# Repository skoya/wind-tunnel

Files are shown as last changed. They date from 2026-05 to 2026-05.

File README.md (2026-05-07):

# KOYA Cooling Stand

Modular OpenSCAD design for a dual Raspberry Pi 5 + UGREEN NVMe + Mac mini M4 airflow stand.

## Hardware concept

- Front 140mm USB-powered fan cools the lower duct.
- UGREEN Thunderbolt/USB-C NVMe enclosure sits below the Pi stacks.
- Two Raspberry Pi 5 + Waveshare PoE M.2 HAT+ B stacks sit above the UGREEN bay.
- Mac mini M4 sits on top in low guide rails.
- Second 140mm fan blows upward toward the Mac mini underside.
- Rear remains open for exhaust and cable routing.

## Main CAD file

Place this in the repo root:

`dual_pi5_macmini_v2_1_corrected_stack_koya.scad`

## Exporting parts

```bash
bash scripts/export_parts.sh dual_pi5_macmini_v2_1_corrected_stack_koya.scad
```

Exports go into `exports/`.

## Validating

```bash
bash scripts/validate_scad.sh dual_pi5_macmini_v2_1_corrected_stack_koya.scad
```

## Important

The assembly export is for inspection only. Print individual parts.

### Support-light base notes

The Pi cassette support is now a separate `pi_frame_bridge` part. The base has four low PLA clip pegs around the UGREEN bay, avoiding the old integrated cantilever gantry and avoiding screws/inserts.

Recommended print/assembly order:

1. Print `base_duct.stl` upright.
2. Print `pi_frame_bridge.stl` as exported; it is flipped upside-down so the cross beams sit on the bed and the posts grow upward.
3. Press the Pi frame C-slotted feet down over the four tapered PLA pegs on the base.
4. Slide/fit the Pi cassettes into the removable frame.

Cable management in the base should use the floor zip-tie slots rather than printed overhanging cable lips.

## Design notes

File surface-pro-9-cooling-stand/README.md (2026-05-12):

# Surface Pro 9 heatsink/fan cooling stand

Current recommended version: **v2**.

Designed around Bobby's actual stack:

- Surface Pro 9 rests directly on aluminium.
- Heatsink: **300 x 140 x 20 mm**, flat face up.
- Noctua fan: **200 x 200 x 30 mm** underneath.
- Printed parts locate/support the metal and fan; they do **not** sit between Surface and heatsink.

## v3 - smoother enclosed version

Current aesthetic candidate: **v3**.

v3 keeps the v2 airflow/fastening logic but makes the stand less like scaffolding:

- rounded charcoal side shrouds and front/rear fascias;
- warm Noctua-style accent on the front catch and removable dust grille;
- fan is mostly hidden in normal use;
- side/front/rear vents keep airflow moving without exposing the whole fan;
- removable `bottom_dust_grille_v3.stl` lets you access the fan for dust cleaning;
- Surface still touches only the exposed aluminium heatsink.

Print for v3:

- `left_rail_v3.stl`
- `right_rail_v3.stl`
- `fan_tray_front_v3.stl`
- `fan_tray_rear_v3.stl`
- `front_lip_v3.stl`
- `rear_keeper_v3.stl`
- `bottom_dust_grille_v3.stl`

Inspect:

- `surface9_heatsink_fan_stand_v3.scad`
- `assembly_v3.stl`
- `preview_v3.png`
- `surface-pro-9-cooling-stand-v3.zip`

## Why v2 exists

v1 proved the layout, but had two real problems:

1. The fan did not have an explicit intake path if the tray sat flat on a desk.
2. The parts were not clearly fastened together.

v2 fixes both.

## v2 parts to print

Print these:

- `left_rail_v2.stl`
- `right_rail_v2.stl`
- `fan_tray_front_v2.stl`
- `fan_tray_rear_v2.stl`
- `front_lip_v2.stl`
- `rear_keeper_v2.stl`

Inspection/reference:

- `surface9_heatsink_fan_stand_v2.scad`
- `assembly_v2.stl` - assembled preview with reference solids for fan/heatsink/Surface
- `printable_frame_v2.stl` - assembled printed parts only

## v2 airflow

The fan tray is lifted **14mm off the desk** on printed feet. That creates an underside intake plenum so the 200mm fan can draw air from below instead of being choked against the table.

Air path:

`room air -> 14mm underside plenum -> fan -> 6mm upper gap -> heatsink fins/underside -> out through open sides/front/rear`

The fan opening is cut through the tray, and the sides are deliberately open rather than boxed in.

## v2 attachment scheme

Use M3 screws/nuts, small self-tappers, or zip ties through the provided holes. Screws are cleaner; zip ties are fine for a first fit.

- **Fan tray front + rear halves**
  - Overlap at the centre seam.
  - Use the centre tab holes to bolt/zip-tie the two halves together.

- **Fan to tray**
  - Fan holes include common 200mm fan mount patterns: **154mm** and **170mm** square.
  - Use whichever aligns with the Noctua frame.

- **Rails to tray**
  - Left/right rails now have inward outrigger tabs.
  - These align with holes near the left/right edges of the fan tray.
  - This turns the tray and rails into one assembly, rather than loose parts around the heatsink.

- **Front lip to tray**
  - The front lip has two vertical risers that bolt/zip-tie down into the front tray holes.
  - Its upper catch stops the Surface sliding forward.

- **Rear keeper to tray**
  - The rear keeper has two vertical risers that bolt/zip-tie into the rear tray holes.
  - It locates the heatsink from the back without touching the Surface face.

- **Heatsink**
  - Drops into the rails, flat face up.
  - Printed shelves/posts support the edges/underside.
  - The aluminium top remains exposed and is the tablet contact surface.

## Print guidance

- PETG, ABS, or ASA preferred. PLA may creep over time near heat.
- 0.2mm layers, 3-4 perimeters, 25-35% infill.
- Fan tray halves are about **216 x 108 x 23mm** each.
- Rails are about **78 x 174 x 72mm** each.
- Lip/keeper include vertical risers; use brim if your printer dislikes tall narrow pieces.

## Files

The original v1 files are retained for comparison. Use v2 unless you specifically want the simpler unfastened concept.

## v4 - lighter shrouded version

v4 reduces material versus v3 while keeping the same overall concept:

- thinner fan tray and dust grille;
- side shrouds changed from mostly solid skirts into ribs/stringers;
- front/rear fascias are hollowed from behind;
- smaller support posts and lighter screw pads;
- fan remains mostly hidden in normal use;
- airflow still uses underside intake, side/front/rear exits, and the removable bottom grille.

Print for v4:

- `left_rail_v4.stl`
- `right_rail_v4.stl`
- `fan_tray_front_v4.stl`
- `fan_tray_rear_v4.stl`
- `front_lip_v4.stl`
- `rear_keeper_v4.stl`
- `bottom_dust_grille_v4.stl`

Inspect:

- `surface9_heatsink_fan_stand_v4.scad`
- `assembly_v4.stl`
- `printable_frame_v4.stl`
- `preview_v4.png`
- `surface-pro-9-cooling-stand-v4.zip`

v4 is the best current candidate if material use matters. v3 is smoother/more enclosed; v4 is lighter and more vented.

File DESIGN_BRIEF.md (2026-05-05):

# DESIGN_BRIEF.md

## Goal

Create a desk-friendly, serviceable, modular cooling stand for:
- 2× Raspberry Pi 5 units with Waveshare PoE M.2 HAT+ B
- 1× UGREEN Thunderbolt/USB-C NVMe enclosure
- 1× Apple Mac mini M4

## Layout

```text
SIDE VIEW

        Mac mini M4
   ┌─────────────────┐
   │  top guide rails │
   ├──── top fan ─────┤  upward airflow
   │ removable lid    │
┌──┴─────────────────┴──┐
│   Pi cassette  Pi cassette │
│                         │
│      UGREEN raised bay   │
│                         │
│ front 140mm fan  → rear exhaust/cables
└─────────────────────────┘
```

## Critical corrections from earlier versions

- UGREEN must be below the Pis.
- Pis must sit above the UGREEN bay.
- KOYA grille must be clipped inside the front cassette.
- Mac mini support must not block central underside airflow.
- The whole design must be modular, not one solid object.

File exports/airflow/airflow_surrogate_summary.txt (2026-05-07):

KOYA airflow surrogate check
Method: 2D pressure/velocity solve on simplified CAD slices; qualitative only.

Pi envelope used: x L 33.0-67.0, x R 87.0-121.0, y 66.0-151.0, z 61.0-117.0 mm (56mm high).
UGREEN envelope: x 52.0-102.0, y 64.0-186.0, z 19.0-43.0 mm.
Top fan underside starts at z 135.0; clearance above Pi top: 18.0 mm.

Plan-slice front flux distribution just upstream of Pi fronts:
  left_outer: 32.1%
  left_pi_front_zone: 7.5%
  centre_gap_between_pis: 20.7%
  right_pi_front_zone: 7.5%
  right_outer: 32.1%

Relative speed metrics around Pi zone:
  left Pi side-surface speed: 0.1227
  right Pi side-surface speed: 0.1225
  centre gap speed: 0.0294
  outer bypass speed: 0.0205

Side-slice outlet split, relative flux:
  through Pi stack slice, solid UGREEN: rear 55.6%, top 44.4%
  through Pi stack slice, vented UGREEN: rear 59.2%, top 40.8%
  through centre gap slice, solid UGREEN: rear 48.4%, top 51.6%
  through centre gap slice, vented UGREEN: rear 52.0%, top 48.0%

UGREEN vent pass-through check:
  Model assumption: three front-to-back vent bands through the UGREEN envelope; real adapters/internal PCB will reduce this.
  mean relative speed inside vent bands under Pi slice: 0.1840
  mean relative speed inside vent bands through centre gap slice: 0.1831
  result: if the real UGREEN vents align front-to-back, fan pressure should push some air through them.
  caution: if vents are only side/top vents rather than front/rear pass-through, the front fan will mostly flow around/under/over the UGREEN, not through it.

Interpretation hints:
  High centre-gap speed compared with Pi side speed means air prefers the gap between Pis.
  High outer-bypass speed means side leakage around the Pi stacks.
  Side slices show whether top fan/rear outlet pull flow over or around the Pi height.

Generated images:
  exports/airflow/plan_slice_at_pi_height.png
  exports/airflow/side_slice_through_pi_stack_solid_ugreen.png
  exports/airflow/side_slice_through_pi_stack_vented_ugreen.png
  exports/airflow/side_slice_through_centre_gap_solid_ugreen.png
  exports/airflow/side_slice_through_centre_gap_vented_ugreen.png

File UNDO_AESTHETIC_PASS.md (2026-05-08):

# Undo aesthetic pass

Created before changing CAD:
- Backup branch: backup/pre-aesthetic-20260508-194037
- Previous preview-latest target: preview-v2-35-modular-base-20260507-082546
- Aesthetic preview target: preview-v2-36-aesthetic-pass-20260508-200048

To undo local CAD edits and restore the previous preview pointer:

```bash
git reset --hard ef0b8f84b5985a6ae9eca44105e914f73c120e5e
git restore dual_pi5_macmini_v2_1_corrected_stack_koya.scad
ln -sfn preview-v2-35-modular-base-20260507-082546 preview-latest
```

If a commit gets made for the aesthetic pass, reset/revert to the backup branch instead:

```bash
git reset --hard backup/pre-aesthetic-20260508-194037
ln -sfn preview-v2-35-modular-base-20260507-082546 preview-latest
```

## Undo dual NF-F12 top update

Created before changing for the two Noctua NF-F12 fans:
- Backup branch: backup/pre-nf-f12-dual-top-20260508-201414
- Previous preview-latest target before NF-F12 update: preview-v2-36-aesthetic-pass-20260508-200048
- NF-F12 preview target: preview-v2-37-dual-nf-f12-top-20260508-203432

To undo only the NF-F12 edit before it is pushed, reset/revert this latest commit once created, or restore from the backup branch above and reset preview-latest:

```bash
git reset --hard backup/pre-nf-f12-dual-top-20260508-201414
ln -sfn preview-v2-36-aesthetic-pass-20260508-200048 preview-latest
```

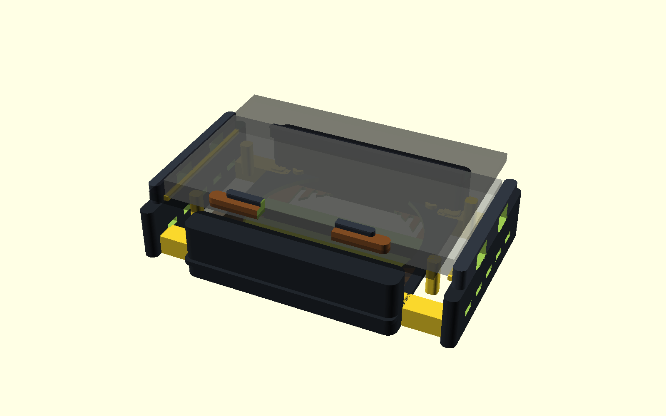
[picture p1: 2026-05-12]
surface-pro-9-cooling-stand/preview_v3.png

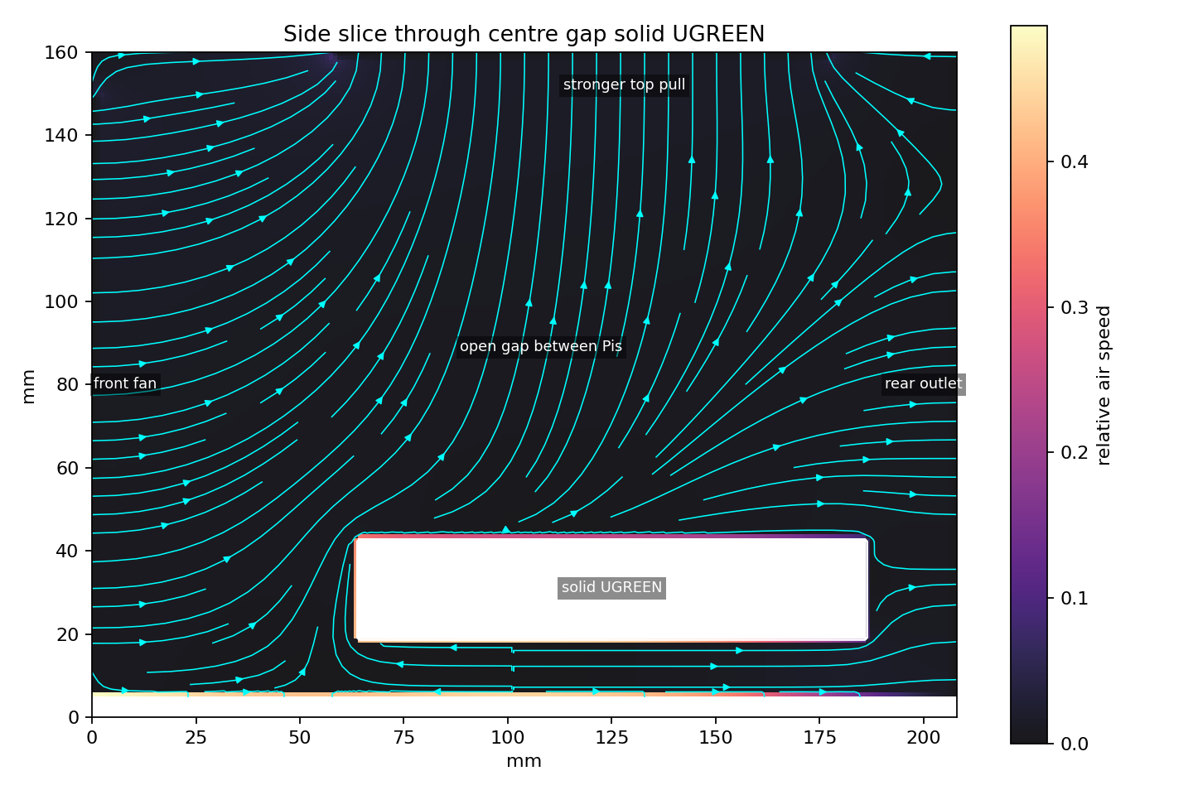
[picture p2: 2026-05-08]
exports/airflow/side_slice_through_centre_gap_solid_ugreen.png

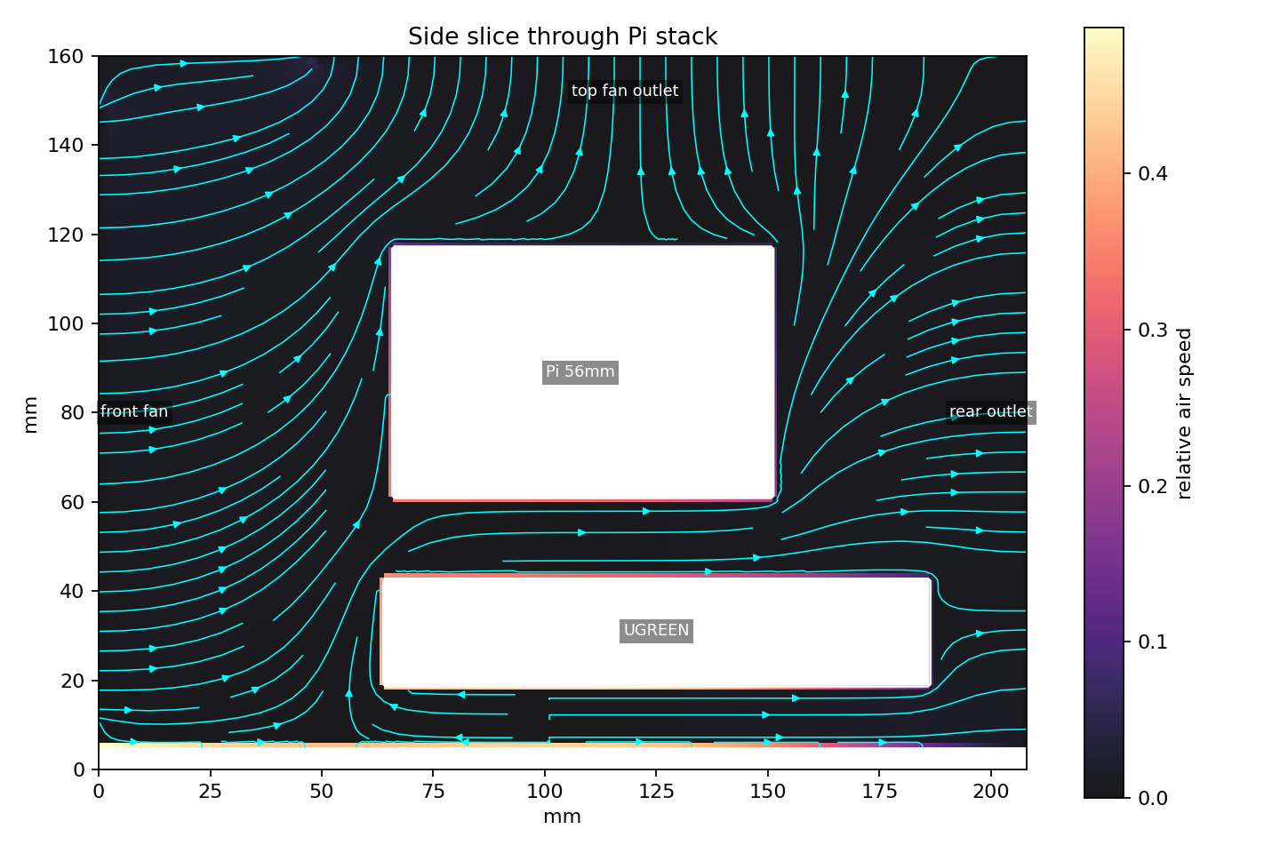
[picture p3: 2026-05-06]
exports/airflow/side_slice_through_pi_stack.png

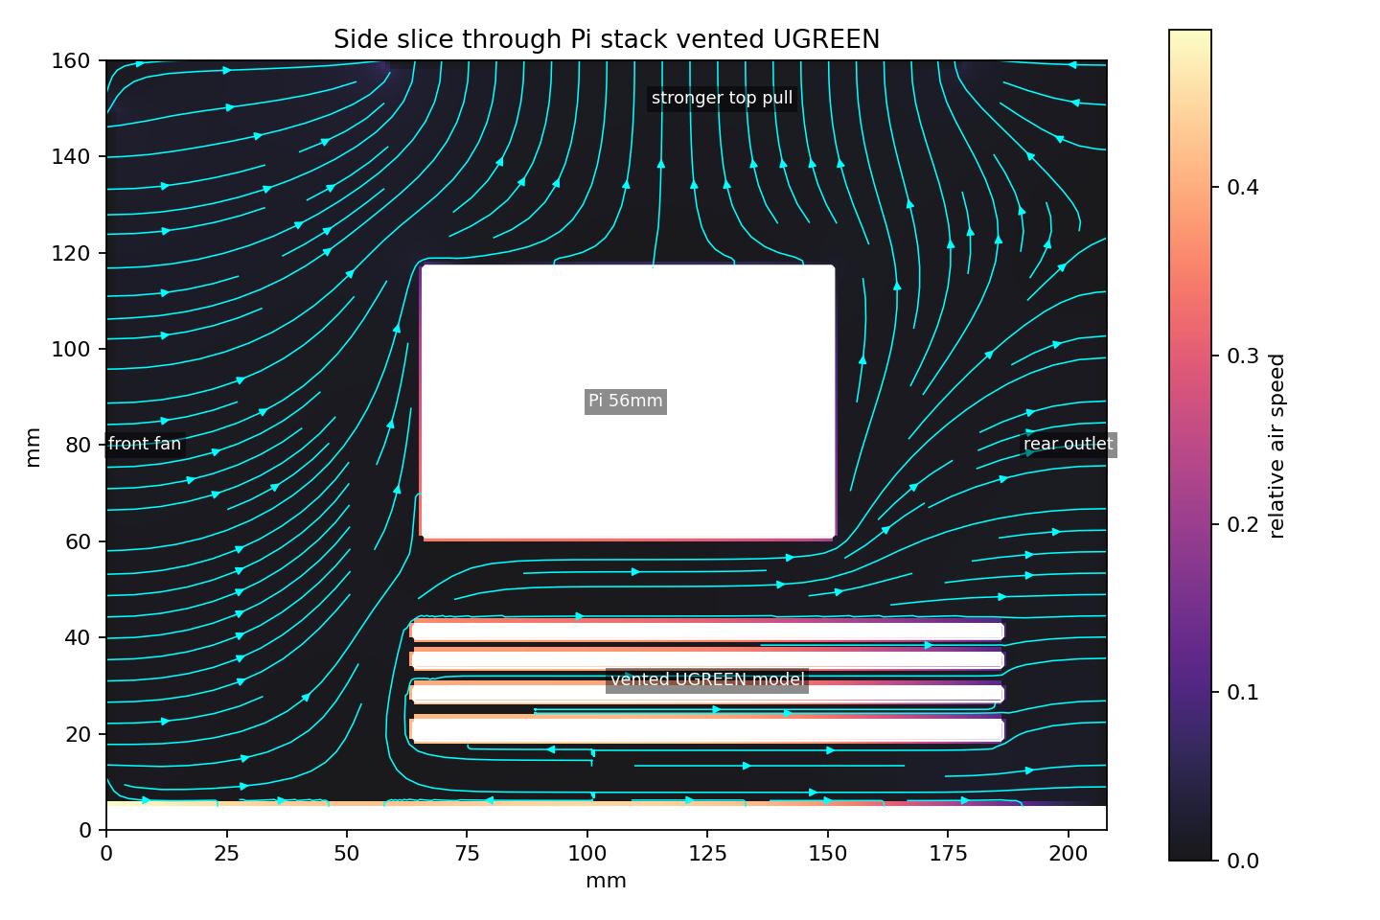
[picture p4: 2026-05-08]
exports/airflow/side_slice_through_pi_stack_vented_ugreen.png

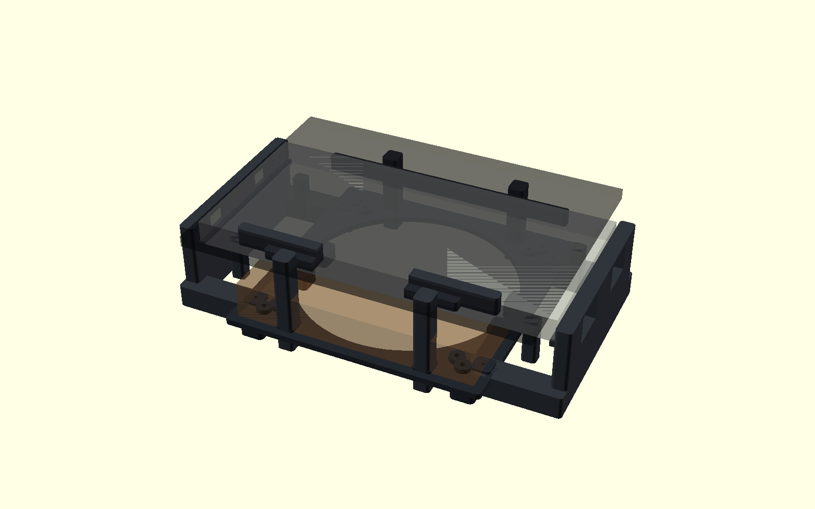
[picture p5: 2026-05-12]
surface-pro-9-cooling-stand/preview_v2.png

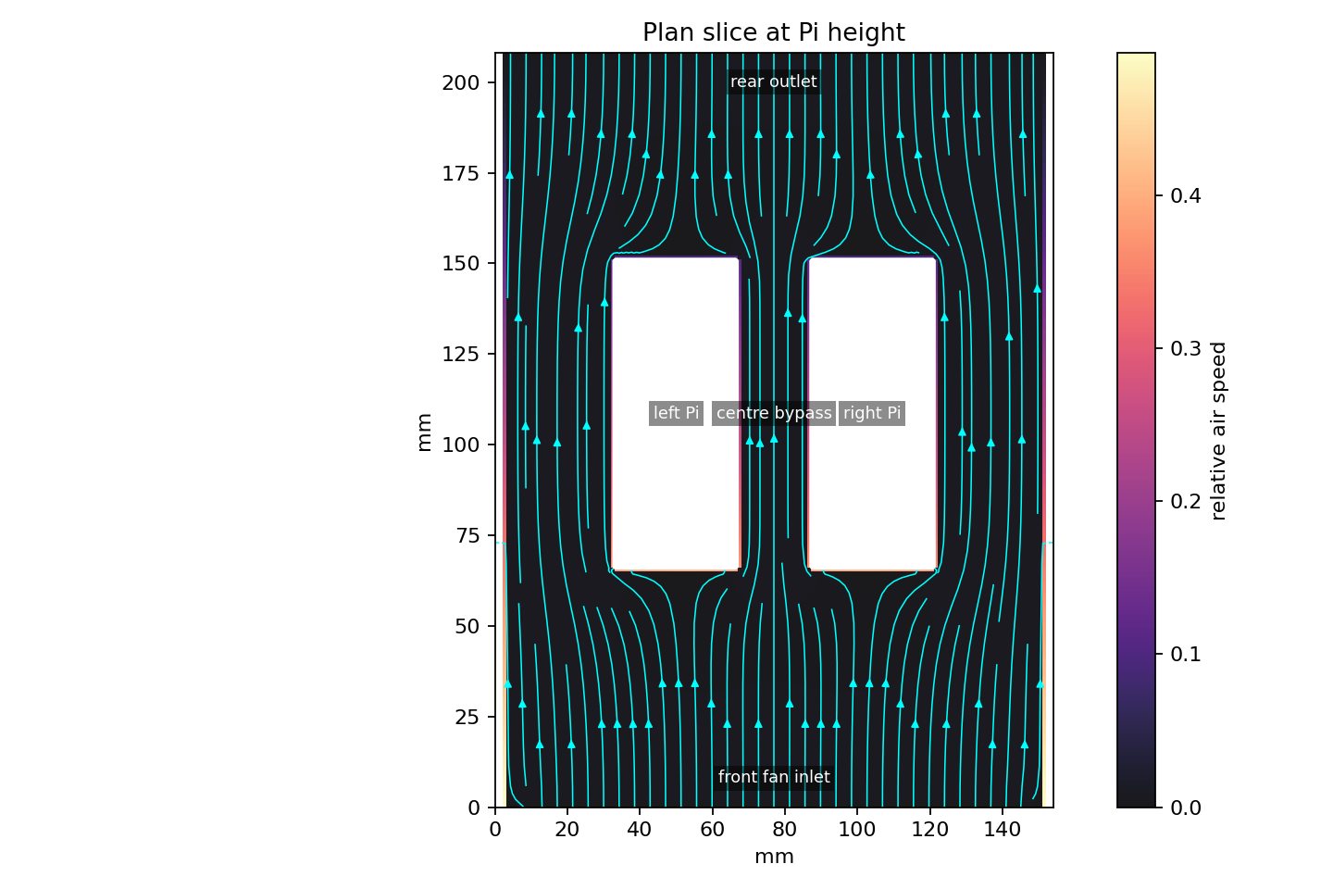
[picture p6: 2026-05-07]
exports/airflow/plan_slice_at_pi_height.png

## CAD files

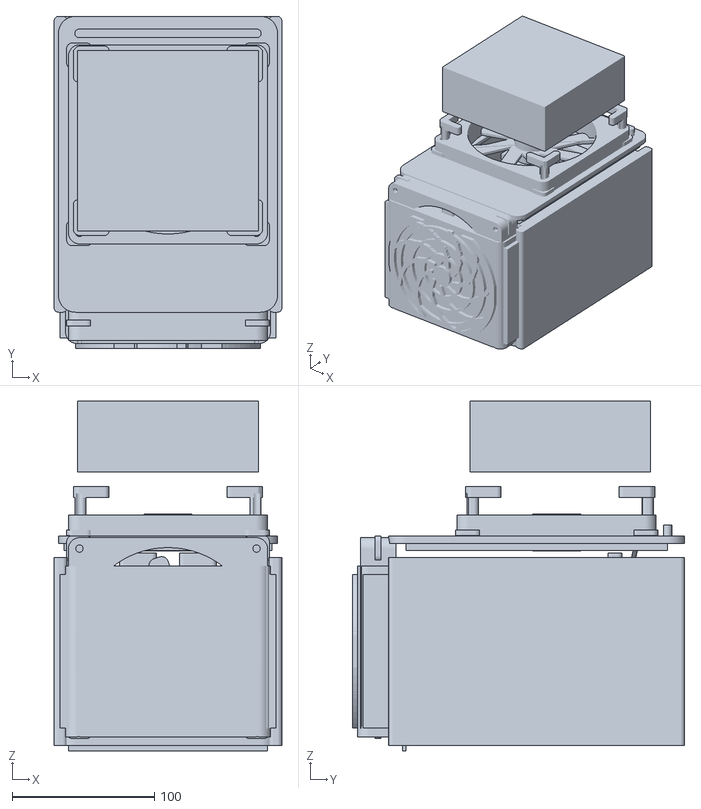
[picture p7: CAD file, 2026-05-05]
exports/inspection/koya_assembly_inspection.stl
160.0 x 233.6 x 246.0

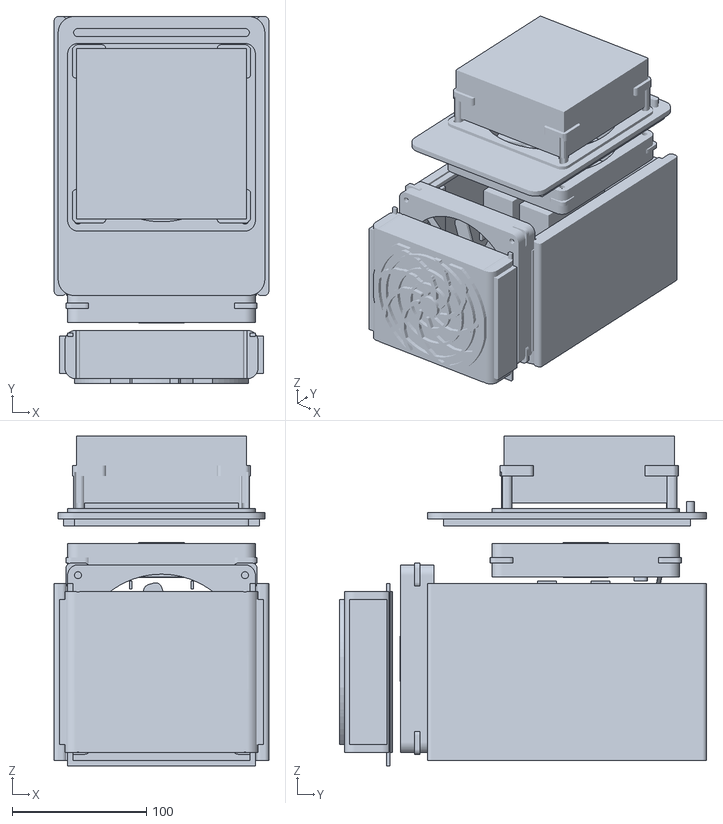
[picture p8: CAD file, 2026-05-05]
exports/inspection/koya_assembly_exploded.stl
160.0 x 273.6 x 246.0

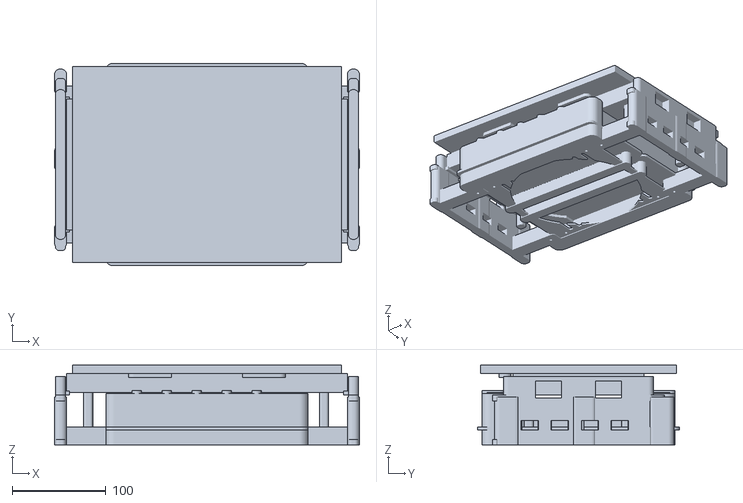
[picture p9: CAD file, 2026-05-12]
surface-pro-9-cooling-stand/assembly_v4.stl
326.0 x 216.0 x 85.5

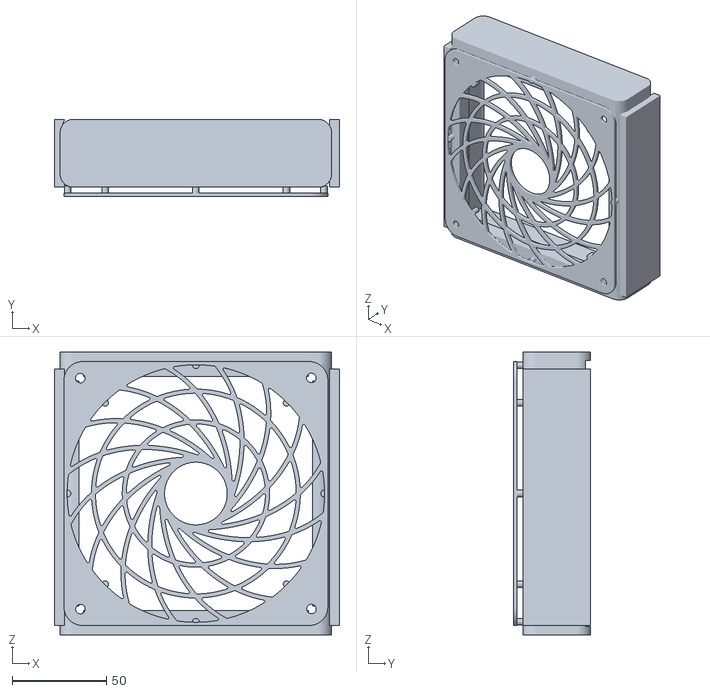
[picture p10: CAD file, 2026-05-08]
exports/front_fan_cassette.stl
151.2 x 41.0 x 150.0

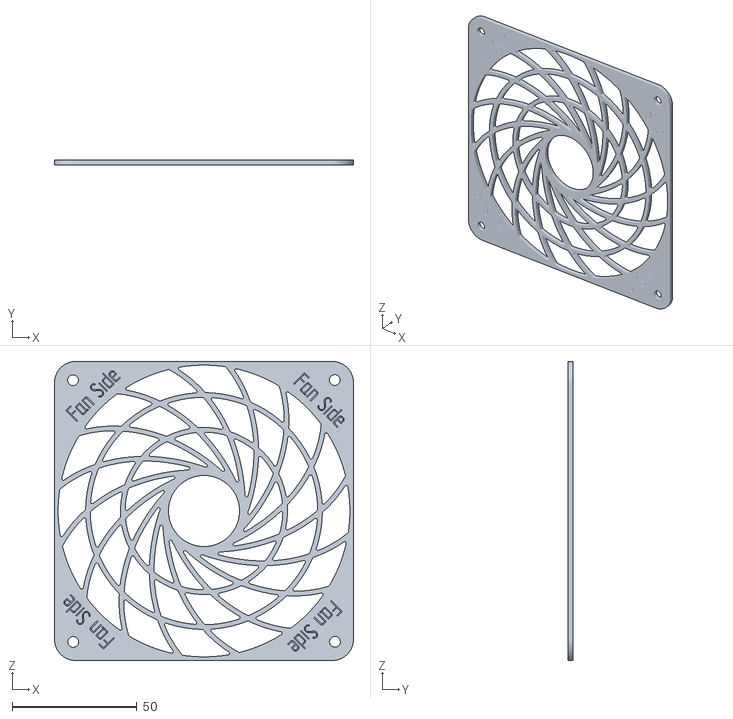
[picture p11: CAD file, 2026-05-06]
references/noctua_120mm_high_efficiency_grill.stl
120.0 x 2.00 x 120.0

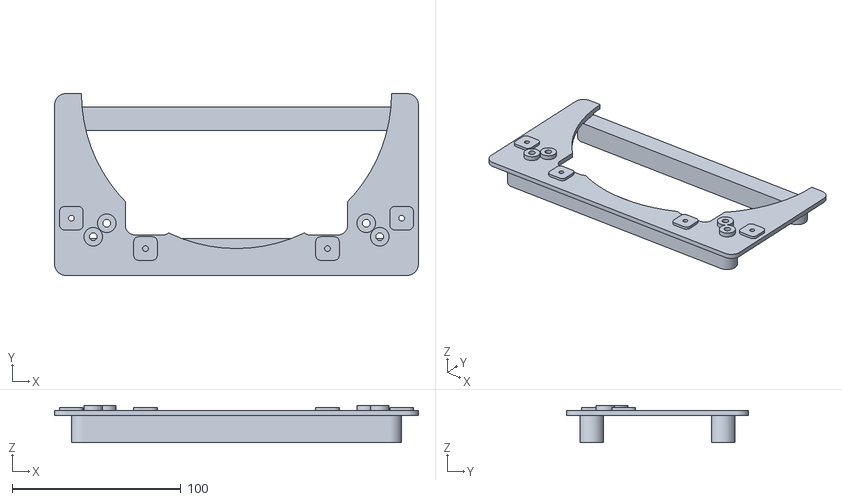
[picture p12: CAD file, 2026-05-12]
surface-pro-9-cooling-stand/fan_tray_front_v4.stl
216.0 x 108.0 x 22.2

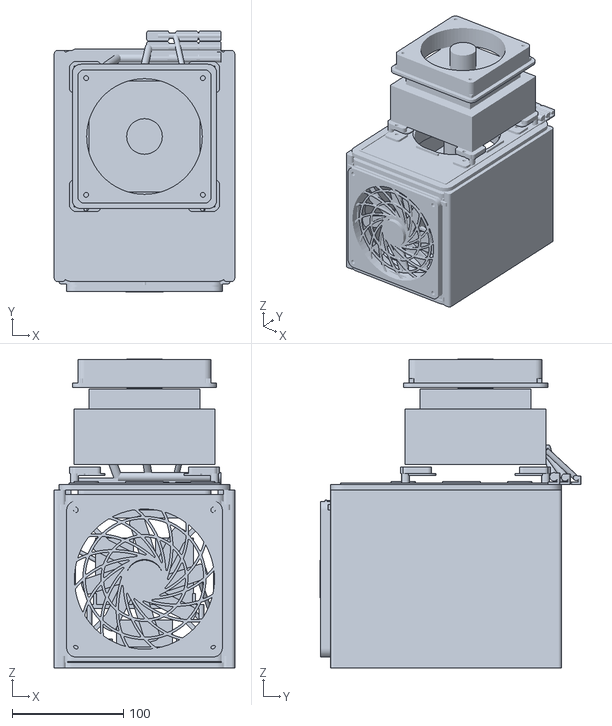
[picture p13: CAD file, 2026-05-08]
exports/fitted_with_hardware_preview.stl
162.4 x 235.0 x 278.0

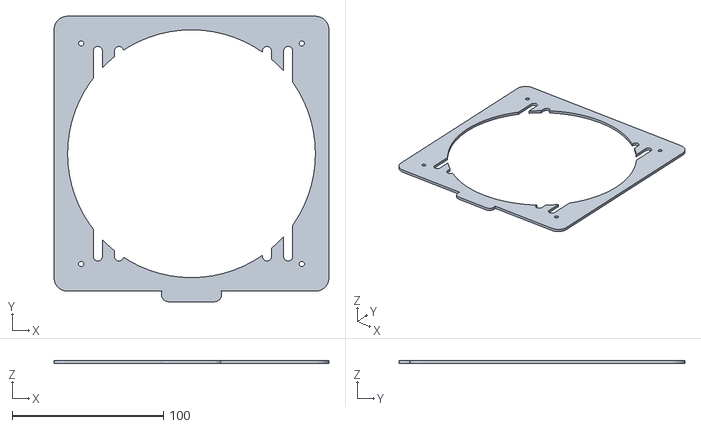
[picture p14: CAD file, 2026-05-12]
surface-pro-9-cooling-stand/bottom_dust_grille_v4.stl
182.0 x 189.0 x 2.20

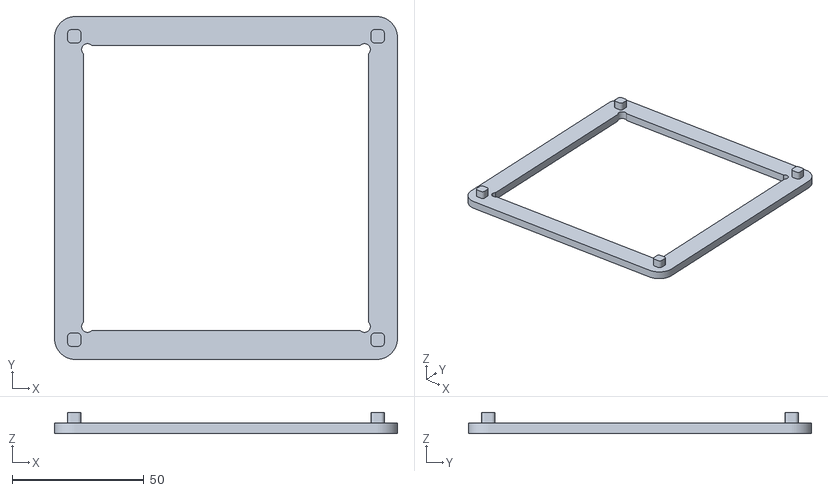
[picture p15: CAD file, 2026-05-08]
exports/upper_mac_fan_bridge.stl
130.0 x 130.0 x 8.00

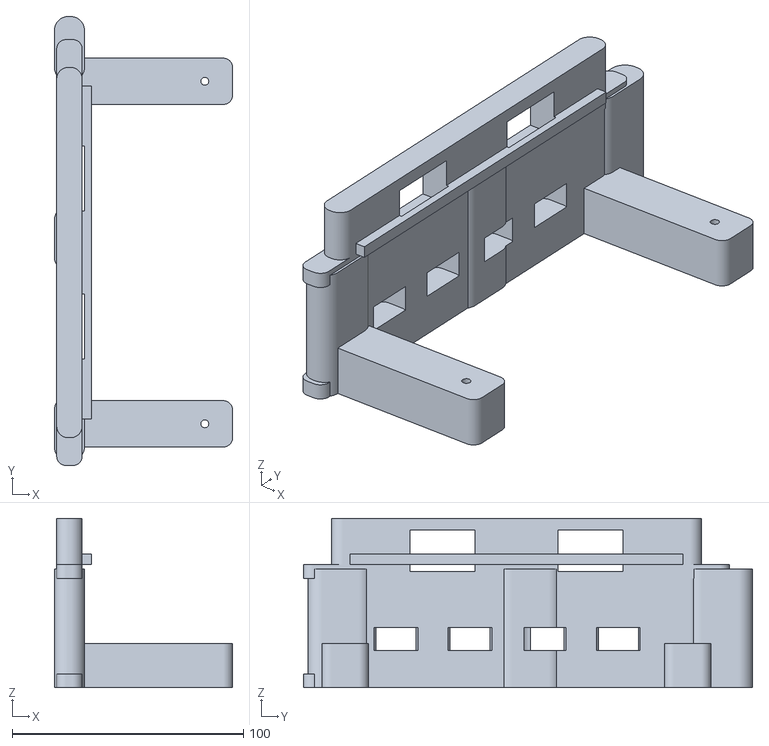
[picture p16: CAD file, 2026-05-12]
surface-pro-9-cooling-stand/left_rail_v4.stl
77.0 x 194.0 x 73.2

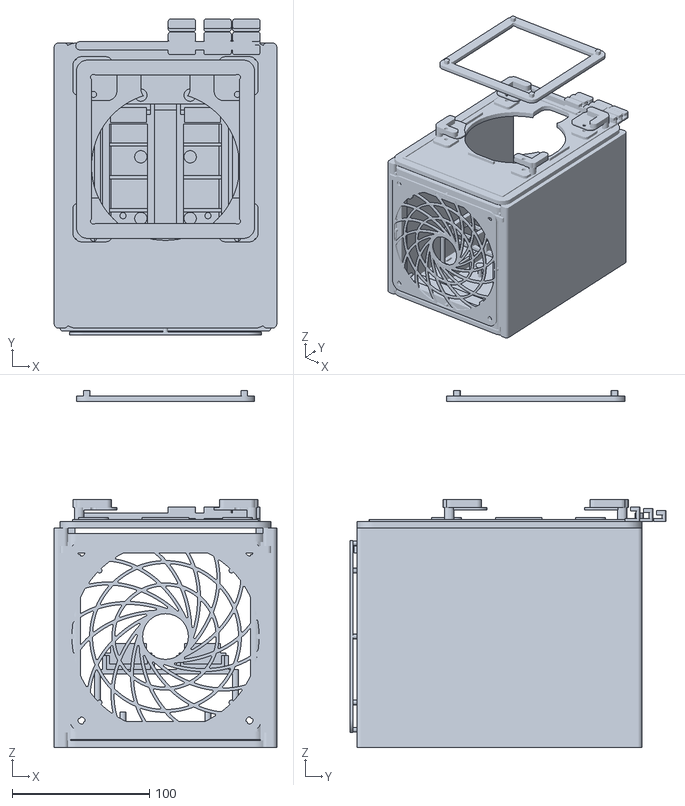
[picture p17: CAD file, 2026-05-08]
exports/fitted_parts_preview.stl
162.4 x 230.5 x 260.5

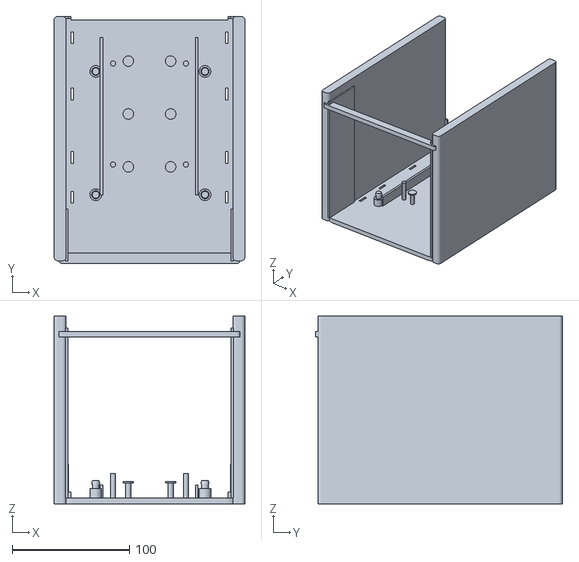
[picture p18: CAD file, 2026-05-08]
exports/base_duct.stl
162.4 x 210.3 x 160.0

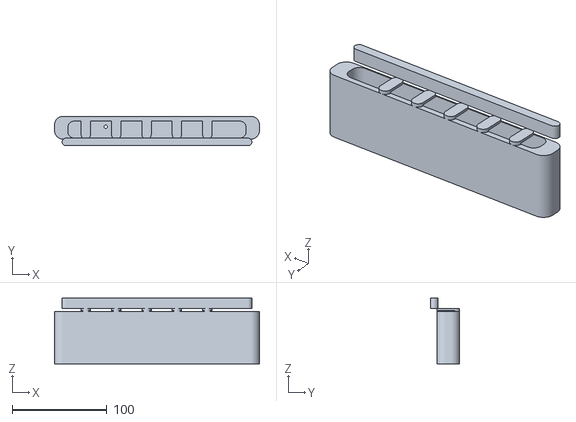
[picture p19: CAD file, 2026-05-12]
surface-pro-9-cooling-stand/rear_keeper_v4.stl
216.0 x 31.0 x 69.2

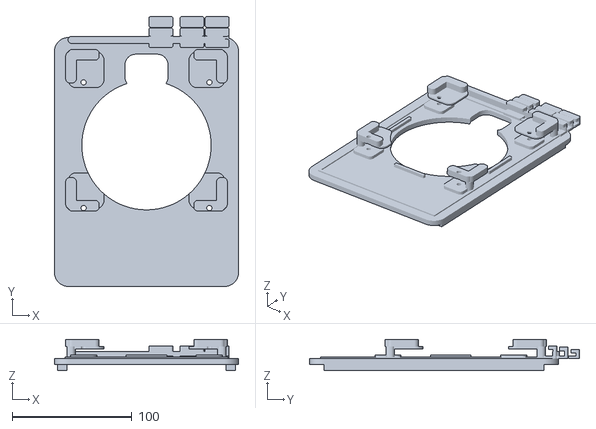
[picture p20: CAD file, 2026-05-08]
exports/lid_mac_saddle.stl
154.0 x 225.5 x 26.0

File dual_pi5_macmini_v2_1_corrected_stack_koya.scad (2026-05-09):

// dual_pi5_macmini_v2_1_corrected_stack_koya.scad
//
// Latest v2.2:
// - 140mm front fan-sized pressure duct.
// - UGREEN TB/NVMe enclosure sits BELOW the Pi cassettes.
// - Pi cassettes sit ABOVE the UGREEN cradle.
// - Front patterned grille is clipped/contained within the cassette face: no overspill.
// - Mac mini M4 saddle is corner-guide only, with large open centre + 140mm upward fan.
// - Rear is open for exhaust and cable access.
// - UGREEN sits loose in a low side-keeper cradle; straps/towers removed.
// - v2.3 tightens physical fit: real cassette slots, lower Pi pull tabs, corrected ghosts.
// - v2.4 restores a real 140mm front fan envelope and hollow rear fan pocket.
// - v2.5 adds printable gantry supports under the elevated Pi cassette guides.
// - v2.6 mounts the top fan under the lid, clearing Pi cassettes and preserving Mac airflow.
// - v2.7 removes disconnected STL islands and rebuilds grille/connectivity.
// - v2.8 reduces material and uses a Noctua-inspired smooth radial intake grille.
// - v2.9 imports the real Noctua 120mm high-efficiency grille STL, scaled for 140mm.
// - v2.10 makes the Noctua grille a separate removable front part so airflow is visibly open.
// - v2.11 rebuilds the front cassette as an open frame with integrated Noctua grille overlay.
// - v2.12 simplifies Pi cassettes and adds fitted/full-hardware preview modes.
// - v2.13 trims plastic while preserving PETG-safe wall/post thickness.
// - v2.14 flips the Noctua grille so the fan-side profile faces inward toward the fan.
// - v2.15 slims walls/front clips and adds Noctua USB fan-cable routing clips.
// - v2.16 lowers Mac mini elevation while preserving a clear top-fan outlet plenum.
// - v2.17 vents Pi cassette trays, removes UGREEN straps/towers, adds top Noctua grille.
// - v2.18 aesthetic pass: calmer side strakes, cleaner front brow, and a floating Mac halo.
// - v2.19 accommodates Noctua NF-F12 120x25mm fans above the Mac and under the top lid.
// - v2.20 adds a rear mechanical rocker for the Mac mini M4 underside power button.
// - Airflow-optimised internals keep UGREEN front/rear/underside grilles open.
// - Open front-to-back duct keeps airflow unobstructed; Pi guide vanes removed.
// - Part envelopes are asserted against the Bambu Lab P1S build volume.
// - Export each part separately using EXPORT_PART.
//
// EXPORT_PART:
// "assembly", "base_duct", "front_fan_cassette", "lid_mac_saddle",
// "pi_cassette_left", "pi_cassette_right", "front_noctua_grille",
// "front_cassette_with_grille", "assembly_exploded", "all_print_parts"

$fn = 72;
EXPORT_PART = "assembly";
SHOW_GHOSTS = true;

// -------------------------
// Core dimensions
// -------------------------
wall = 1.8;       // ~4-5 perimeters with 0.4mm nozzle; PETG-safe but less chunky
floor_h = 4;    // support/material-light floor; rely on walls/infill for stiffness
corner_r = 12;

// Aesthetic skin details are shallow, non-structural, and easy to revert.
// They sit outside the airflow path: no internal fins, no extra fan blockage.
aesthetic_skin_t = 1.2;
aesthetic_strake_h = 2.2;
aesthetic_strake_r = 1.1;
aesthetic_brow_h = 5;
clearance = 0.6;
join_clearance = 0.45; // loose printed clearance for removable slide/drop-in joins

fan_size = 140;
fan_thick = 25;
fan_mount_spacing = 124.5; // verify your exact 140mm front fan
fan_screw_d = 5.2;

// Top-base fan is now a Noctua NF-F12, not the previous 140mm fan.
top_base_fan_size = 120;
top_base_fan_thick = 25;
top_base_fan_mount_spacing = 105;
top_base_fan_screw_d = 4.4;
top_base_fan_opening = 108;
noctua_grill_ref = "references/noctua_120mm_high_efficiency_grill.stl";
noctua_grill_scale = fan_size / 120;

// Bambu Lab P1S nominal build volume, used for part envelope asserts.
p1s_build_x = 256;
p1s_build_y = 256;
p1s_build_z = 256;

// Apple Mac mini M4 official body: 127 x 127 x 50mm
mac_w = 127;
mac_d = 127;
mac_h = 50;
mac_clearance = 2;

// Main duct hugs 140mm fan envelope
body_w = 154;     // 140 + side structure
body_d = 208;
body_h = 160;     // leaner height; still leaves clearance over Pi cassettes and under-lid top fan

front_cassette_d = 36;
front_tongue_w = 3.2;
front_tongue_h_margin = 5;
front_fan_pocket_clearance = 1.0;
front_fan_pocket_d = fan_thick + 1.2; // rear pocket accepts a 25mm-thick 140mm fan
front_grille_standoff = 3.0; // grille sits outside/front of fan cassette
rear_plenum_d = 28;
rear_y = body_d - rear_plenum_d;

// Lower UGREEN bay
ugreen_l = 122;   // placeholder; measure real enclosure without silicone
ugreen_w = 50;
ugreen_h = 24;
ugreen_y = front_cassette_d + 28;
ugreen_air_under = 14;
ugreen_z = floor_h + ugreen_air_under; // underside airflow
ugreen_top_clearance = 14;
ugreen_peg_d = 4.5;
ugreen_pad_d = 9;
ugreen_side_keeper_h = 7;

// Upper Pi bay: cassettes sit above UGREEN, not beside/inside it
pi_stack_t = 34;       // assembled Pi + HAT stack thickness across cassette width; verify real build
pi_card_d = 92;
pi_body_h = 56;        // measured installed Pi stack height
pi_card_h = pi_body_h + 2; // small visual/mechanical envelope allowance
pi_gap = 20; // widened centre gap between Pi cassettes for airflow/cable access
pi_y = front_cassette_d + 26;
pi_z = ugreen_z + ugreen_h + ugreen_top_clearance;
pi_lower_guide_h = 10;
pi_upper_keeper_h = 6;
pi_guide_t = 3;
pi_support_post_t = 4.5;
pi_support_beam_h = 3.5;
pi_support_front_y = pi_y - 8;
pi_support_rear_y = pi_y + pi_card_d + 5;
pi_frame_socket_h = 4.5;     // shallow floor sockets; no tall random base poles
pi_frame_socket_boss_d = 10;
pi_frame_socket_d = 7.4;     // leg diameter + clearance
pi_frame_leg_d = 6.6;
pi_frame_leg_clearance = 0.8;
pi_pull_tab_h = 7;       // kept low so installed cassette clears a seated lid
pi_pull_tab_overhang = 6; // rear grip lip, below lid envelope

// Front grille and filter pocket.
// Printed grille is a finger guard and filter support; use removable foam/mesh
// filter media in the rear pocket for real dust capture.
filter_panel_w = 132;
filter_panel_h = 132;
filter_media_t = 2.0;
filter_slot_clearance = 0.5;
filter_channel_w = 4;
pattern_bar_t = 2.2;
grille_spoke_t = 2.4;
grille_swirl_count = 9;
grille_swirl_t = 4.0;
grille_swirl_twist = 1.45;

// Fan cable routing: clips are kept on side walls, outside the main airflow stream.
fan_wire_d = 3.5;
mac_power_cable_d = 7.5; // approximate Mac mini mains lead diameter; holder is intentionally generous
mac_usbc_cable_d = 4.8;  // typical USB-C cable diameter
mac_rj45_cable_d = 6.5;  // ethernet cable, not the RJ45 plug body
wire_clip_gap = 6.8; // generous snap-in throat for ~3.5mm fan lead after PETG shrink/stringing
wire_clip_t = 2.2;
wire_clip_h = 11;
wire_clip_depth = 9.5;
front_fan_wire_side_x = body_w - wall - wire_clip_depth/2 + 0.6;
top_fan_wire_side_x = wall + wire_clip_depth/2 - 0.6;
fan_wire_z = 18;
top_fan_wire_z = body_h - 10;
usb_rear_y = body_d - 18;
top_fan_pi_usb_z = pi_z + 36; // approximate Pi USB cable entry height at rear of cassette
top_fan_pi_usb_x = body_w/2 - pi_gap/2 - 10; // default route to left Pi; mirror manually if needed

// Mac saddle / top fan
top_lid_thick = 5;
top_fan_y = 58;
top_fan_locator_h = 3;   // low top-side screw pads/locators only
mac_air_gap = 10;        // modest outlet plenum above lid; top fan is under the lid
mac_saddle_w = mac_w + mac_clearance*2;
mac_saddle_d = mac_d + mac_clearance*2;
mac_saddle_x = (body_w - mac_saddle_w)/2;
mac_saddle_y = top_fan_y + 7;
mac_deck_lift = 0; // Mac guides sit flush on the lid/roof; fan remains mounted underneath
mac_rail_h = 6;
mac_rail_t = 5;
mac_riser_t = 5;
top_grille_standoff = 0; // top grille removed: Mac is supported by rails, leaving fan outlet open

// Clip-on upper cooler for Mac mini + heatsink + one Noctua NF-F12 fan.
// This is a separate printable bridge so the Mac can still slide out of the saddle.
heatsink_w = 100;
heatsink_d = 100;
heatsink_h = 18;
heatsink_clearance = 3;
upper_fan_size = 120;          // Noctua NF-F12: 120 x 120 x 25mm
upper_fan_thick = 25;
upper_fan_mount_spacing = 105; // Noctua NF-F12 mounting pattern
upper_fan_screw_d = 4.4;
upper_fan_air_opening = 108;   // leaves material under the fan frame
upper_fan_count = 1;
upper_fan_gap = 0;
upper_fan_margin = 5;
upper_bridge_w = upper_fan_size + upper_fan_margin*2;
upper_bridge_d = upper_fan_size + upper_fan_margin*2;
upper_cooler_leg_t = 5.0;
upper_cooler_frame_t = 5;
upper_bridge_corner_r = 8;
upper_bridge_arch_h = 8; // retained for compatibility; no tall side arches now
upper_cooler_gap = 1.5; // tiny anti-rattle clearance: fan frame effectively rests on heatsink
upper_fan_lip_h = 4; // low retaining lip over fan-frame corners
upper_cooler_h = mac_h + heatsink_h + upper_cooler_gap + upper_fan_thick + upper_fan_lip_h;
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

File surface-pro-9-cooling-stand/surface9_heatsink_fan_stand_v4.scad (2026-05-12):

/* Surface Pro 9 heatsink + Noctua NF-A20 stand - v4 lightweight shroud

v4 objective: keep v3's smoother/hidden-fan look but cut plastic volume.
Changes:
- thinner tray/shroud sections;
- open ribbed side rails instead of solid skirts;
- lighter front/rear fascias with large hidden cut-outs;
- thin removable dust grille;
- same direct aluminium contact surface.
*/

PART="assembly";
$fn=72;

heatsink_w=300; heatsink_d=140; heatsink_h=20;
fan_w=200; fan_d=200; fan_h=30; fan_opening=184;
fan_mount_d=4.6; fan_mount_patterns=[154,170];
surface_w=287; surface_d=209; surface_t=9.3;

rail_w=11; clearance=1;
base_margin=8;
fan_tray_w=fan_w+2*base_margin; //216
fan_tray_d=fan_d+2*base_margin; //216
tray_t=3.2;
intake_gap=16;
air_gap=7;
rib=5;

stand_w=heatsink_w+2*rail_w+2*clearance;
stand_d=fan_tray_d;
tray_x=(stand_w-fan_tray_w)/2;
heatsink_x=(stand_w-heatsink_w)/2;
heatsink_y=(stand_d-heatsink_d)/2;
fan_x=(stand_w-fan_w)/2;
fan_y=(stand_d-fan_d)/2;
tray_z=intake_gap;
fan_bottom_z=tray_z+tray_t;
fan_top_z=fan_bottom_z+fan_h;
heatsink_bottom_z=fan_top_z+air_gap;
contact_z=heatsink_bottom_z+heatsink_h;

body="#20252b"; body2="#303741"; accent="#b66a2c"; metal=[0.72,0.73,0.70,0.60];

module rb(s=[10,10,10],r=3){ hull() for(x=[r,s[0]-r]) for(y=[r,s[1]-r]) translate([x,y,0]) cylinder(h=s[2],r=r); }
module hole(h=20,d=3.4){ cylinder(h=h,d=d); }
module slot(s=[8,30,20],r=3){ rb(s,r); }

module heatsink_reference(){ color(metal) translate([heatsink_x,heatsink_y,heatsink_bottom_z]) cube([heatsink_w,heatsink_d,heatsink_h]); }
module fan_reference(){ color([0.45,0.30,0.16,0.22]) translate([fan_x,fan_y,fan_bottom_z]) cube([fan_w,fan_d,fan_h]); }
module surface_reference(){ color([0.03,0.04,0.05,0.30]) translate([(stand_w-surface_w)/2,heatsink_y-(surface_d-heatsink_d)/2,contact_z]) cube([surface_w,surface_d,surface_t]); }

module fan_tray_half(front=true){
  half_d=fan_tray_d/2; y0=front?0:half_d;
  difference(){
    union(){
      // minimal ring-like half tray
      color(body) translate([0,0,tray_z]) rb([fan_tray_w,half_d,tray_t],7);
      // long skid feet, hollowed by cutouts below
      color(body) translate([10,8,0]) rb([fan_tray_w-20,14,intake_gap],7);
      color(body) translate([10,half_d-22,0]) rb([fan_tray_w-20,14,intake_gap],7);
      // screw pads only where needed
      for(spacing=fan_mount_patterns) for(sx=[-spacing/2,spacing/2]) for(sy=[-spacing/2,spacing/2]){
        yy=fan_tray_d/2+sy-y0; if(yy>=6&&yy<=half_d-6) translate([fan_tray_w/2+sx,yy,tray_z+tray_t]) cylinder(h=3,d=11);
      }
      // seam tabs
      if(front){ translate([24,half_d-7,tray_z]) rb([40,16,tray_t+1.8],4); translate([fan_tray_w-64,half_d-7,tray_z]) rb([40,16,tray_t+1.8],4); }
      else { translate([76,-9,tray_z]) rb([40,16,tray_t+1.8],4); translate([fan_tray_w-116,-9,tray_z]) rb([40,16,tray_t+1.8],4); }
      // attachment pads
      for(x=[10,fan_tray_w-10]) for(gy=[34,fan_tray_d-34]){ yy=gy-y0; if(yy>=8&&yy<=half_d-8) translate([x-7,yy-7,tray_z]) rb([14,14,tray_t+1.8],3); }
      for(x=[54,fan_tray_w-54]) for(gy=[16,fan_tray_d-16]){ yy=gy-y0; if(yy>=8&&yy<=half_d-8) translate([x-7,yy-7,tray_z]) rb([14,14,tray_t+1.8],3); }
    }
    // main fan opening
    translate([fan_tray_w/2,fan_tray_d/2-y0,tray_z-1]) cylinder(h=tray_t+9,d=fan_opening);
    // extra lightening: four corner scallops in tray plate, leaving perimeter/ribs
    for(x=[42,fan_tray_w-70]) for(yy=[24,half_d-48]) translate([x,yy,tray_z-1]) rb([28,24,tray_t+8],6);
    // holes
    for(spacing=fan_mount_patterns) for(sx=[-spacing/2,spacing/2]) for(sy=[-spacing/2,spacing/2]){ yy=fan_tray_d/2+sy-y0; if(yy>=-2&&yy<=half_d+2) translate([fan_tray_w/2+sx,yy,tray_z-1]) hole(tray_t+11,fan_mount_d); }
    if(front) for(x=[44,fan_tray_w-44]) translate([x,half_d+1,tray_z-1]) hole(tray_t+10,3.4);
    else for(x=[98,fan_tray_w-98]) translate([x,-1,tray_z-1]) hole(tray_t+10,3.4);
    for(x=[10,fan_tray_w-10]) for(gy=[34,fan_tray_d-34]){ yy=gy-y0; if(yy>=-2&&yy<=half_d+2) translate([x,yy,tray_z-1]) hole(tray_t+10,3.4); }
    for(x=[54,fan_tray_w-54]) for(gy=[16,fan_tray_d-16]){ yy=gy-y0; if(yy>=-2&&yy<=half_d+2) translate([x,yy,tray_z-1]) hole(tray_t+10,3.4); }
  }
}
module fan_tray_front(){ fan_tray_half(true); }
module fan_tray_rear(){ fan_tray_half(false); }
module fan_tray_assembled(){ translate([tray_x,0,0]) fan_tray_front(); translate([tray_x,fan_tray_d/2,0]) fan_tray_rear(); }

module bottom_dust_grille(){
  difference(){
    union(){ color(accent) rb([fan_tray_w-34,fan_tray_d-34,2.2],9); color(accent) translate([(fan_tray_w-34)/2-20,-7,0]) rb([40,10,2.2],5); }
    translate([(fan_tray_w-34)/2,(fan_tray_d-34)/2,-1]) cylinder(h=5,d=164);
    // radial-ish slats represented as parallel slots
    for(x=[26:14:fan_tray_w-60]) translate([x,20,-1]) rb([6,fan_tray_d-74,5],3);
    for(x=[18,fan_tray_w-52]) for(y=[18,fan_tray_d-52]) translate([x,y,-1]) hole(5,3.4);
  }
}

module side_shroud(left=true){
  x=left?heatsink_x-rail_w-clearance:heatsink_x+heatsink_w+clearance;
  tab_x=left?x:tray_x+fan_tray_w-22;
  tab_w=left?tray_x+22-x:x+rail_w-(tray_x+fan_tray_w-22);
  hole_x=left?tray_x+10:tray_x+fan_tray_w-10;
  difference(){
    union(){
      // top rail around heatsink
      color(body2) translate([x,heatsink_y-10,0]) rb([rail_w,heatsink_d+20,heatsink_bottom_z+heatsink_h-3],5);
      translate([left?heatsink_x-2:heatsink_x+heatsink_w-4,heatsink_y-2,heatsink_bottom_z-3]) cube([5,heatsink_d+4,4.5]);
      // lightweight lower side: three ribs, not a slab
      for(y=[18,stand_d/2-8,stand_d-34]) color(body) translate([x,y,0]) rb([rail_w,28,fan_top_z+2],6);
      // top/bottom stringers hide sightline to fan
      color(body) translate([x,16,fan_top_z-2]) rb([rail_w,stand_d-32,6],4);
      color(body) translate([x,16,0]) rb([rail_w,stand_d-32,6],4);
      for(gy=[34,fan_tray_d-34]) translate([tab_x,gy-10,0]) rb([tab_w,20,tray_z+tray_t],4);
    }
    // more open side slots/cutouts
    for(y=[46,78,110,142]) translate([x-1,y,16]) rb([rail_w+3,20,10],4);
    for(y=[34,fan_tray_d-34]) translate([hole_x,y,-1]) hole(tray_z+tray_t+4,3.4);
    translate([x-1,heatsink_y+24,fan_top_z+1]) cube([rail_w+2,28,18]);
    translate([x-1,heatsink_y+88,fan_top_z+1]) cube([rail_w+2,28,18]);
  }
}

module support_posts(){ post_h=heatsink_bottom_z-(tray_z+tray_t); for(x=[heatsink_x+18,heatsink_x+heatsink_w-30]) for(y=[heatsink_y+12,heatsink_y+heatsink_d-24]) translate([x,y,tray_z+tray_t]) rb([10,10,post_h],3); }

module front_lip(){
  lip_w=216; lip_x=(stand_w-lip_w)/2;
  difference(){
    union(){
      // lightweight fascia: perimeter + ribs rather than solid wall
      color(body) translate([lip_x,5,0]) rb([lip_w,24,fan_top_z+6],9);
      for(x=[lip_x+28:32:lip_x+lip_w-46]) color(body) translate([x,5,0]) rb([10,24,fan_top_z+9],5);
      color(accent) translate([lip_x+24,heatsink_y-15,contact_z-4]) rb([lip_w-48,13,9],6);
    }
    // hollow most of the fascia backside
    translate([lip_x+14,10,9]) rb([lip_w-28,18,fan_top_z-2],7);
    translate([lip_x+70,heatsink_y-20,contact_z-8]) cube([76,26,25]);
    for(x=[lip_x+54,lip_x+lip_w-54]) translate([x,16,-1]) hole(tray_z+tray_t+4,3.4);
  }
}

module rear_keeper(){
  k_w=216; k_x=(stand_w-k_w)/2;
  difference(){
    union(){
      color(body) translate([k_x,stand_d-29,0]) rb([k_w,24,fan_top_z+6],9);
      for(x=[k_x+28:32:k_x+k_w-46]) color(body) translate([x,stand_d-29,0]) rb([10,24,fan_top_z+9],5);
      color(body2) translate([k_x+8,heatsink_y+heatsink_d+2,heatsink_bottom_z+2]) rb([k_w-16,8,11],4);
    }
    translate([k_x+14,stand_d-28,9]) rb([k_w-28,18,fan_top_z-2],7);
    for(x=[k_x+54,k_x+k_w-54]) translate([x,stand_d-16,-1]) hole(tray_z+tray_t+4,3.4);
  }
}

module printable_frame(){ fan_tray_assembled(); side_shroud(true); side_shroud(false); support_posts(); front_lip(); rear_keeper(); translate([tray_x+17,17,1]) bottom_dust_grille(); }
module assembly(){ printable_frame(); heatsink_reference(); fan_reference(); surface_reference(); }

if(PART=="assembly") assembly();
else if(PART=="printable_frame") printable_frame();
else if(PART=="left_rail") side_shroud(true);
else if(PART=="right_rail") side_shroud(false);
else if(PART=="fan_tray_front") fan_tray_front();
else if(PART=="fan_tray_rear") fan_tray_rear();
else if(PART=="front_lip") front_lip();
else if(PART=="rear_keeper") rear_keeper();
else if(PART=="bottom_dust_grille") bottom_dust_grille();
else if(PART=="heatsink_reference") heatsink_reference();
else if(PART=="fan_reference") fan_reference();
else surface_reference();

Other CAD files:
surface-pro-9-cooling-stand/right_rail_v4.stl
surface-pro-9-cooling-stand/fan_tray_rear_v4.stl
exports/mac_upper_cooler_preview.stl
exports/pi_frame_bridge.stl
surface-pro-9-cooling-stand/surface9_heatsink_fan_stand_v1.scad
surface-pro-9-cooling-stand/surface9_heatsink_fan_stand_v2.scad
exports/cable_route_ghosts.stl
exports/front_cassette_with_grille.stl
exports/front_fan_cassette_body.stl
exports/front_noctua_grille.stl
exports/pi_cassette_left.stl
exports/pi_cassette_right.stl
surface-pro-9-cooling-stand/assembly_v1.stl
surface-pro-9-cooling-stand/assembly_v2.stl
surface-pro-9-cooling-stand/assembly_v3.stl
surface-pro-9-cooling-stand/bottom_dust_grille_v3.stl
surface-pro-9-cooling-stand/fan_tray_front_v1.stl
surface-pro-9-cooling-stand/fan_tray_front_v2.stl
surface-pro-9-cooling-stand/fan_tray_front_v3.stl
surface-pro-9-cooling-stand/fan_tray_rear_v1.stl
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

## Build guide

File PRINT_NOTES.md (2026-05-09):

# KOYA Cooling Stand — Bambu/P1S print notes

## Material
- Main parts: PETG recommended.
- PLA is fine for quick fit prototypes, but PETG is safer near warm electronics/fans.

## Support PLA / support interface
STL files cannot reliably encode “use Support PLA here” or assign internal support material. Do this in Bambu Studio/Orca instead:

- Main filament: PETG.
- Support filament/interface: Support PLA or PLA only as **support interface**, not as structural infill.
- Use supports only where slicer genuinely requires them; the model is being kept support-light.
- For PETG + PLA support interface, leave a small interface gap according to your slicer profile and dry both filaments.

Recommended starting point:
- 0.4mm nozzle
- 0.2mm layer height
- 4–5 walls for structural parts
- 20–25% gyroid infill
- 5 top / 5 bottom layers
- For the support-light lid, try supports **off** first; only the rocker hinge holes may need local/manual help depending on slicer settings.
- For the base, keep supports off unless the slicer flags the front cassette receiver rails; the rear is intentionally open now.
- Brim optional for tall parts

## Print orientation
- `base_duct.stl`: flat on base.
- `front_fan_cassette.stl`: rear fan pocket facing up or as slicer suggests; inspect grille bridging.
- `lid_mac_saddle.stl`: flat underside down. The old underside locating tongues were removed because they made the slicer support almost the whole lid.
- `pi_frame_bridge.stl`: as exported; it is flipped upside-down so the cross beams and integrated Pi holder rails sit on the bed and the four straight socket legs grow upward.
- Separate Pi cassette STLs are no longer needed; the Pi holders are integrated into `pi_frame_bridge.stl`.
- `upper_mac_fan_bridge.stl`: flat on the broad bridge face; inspect fan-guard bridging.

## Pi cage fitting

- The base now has four shallow receiver sockets instead of snap pegs or tall poles.
- The removable Pi frame has four straight round legs that drop into those sockets.
- The Pi holder rails/ribs are now part of the removable Pi frame; no separate Pi cassettes/back bars.
- If the fit is too tight/loose, tune `pi_frame_socket_d` or `pi_frame_leg_d` in the SCAD file.

## Mac mini M4 power rocker

- `mac_power_rocker.stl` is a separate moving part.
- Fit it into the rear hinge cheeks on `lid_mac_saddle.stl` with an M3 screw or short filament pin.
- The orange/red preview marker is only an approximate Mac underside power-button target; confirm against the real Mac before committing to a long final print.
- If the button is off, adjust `mac_power_button_x` / `mac_power_button_y` in the SCAD file.

## Reminder
Do not print preview/assembly STLs. They are for visual inspection only. UGREEN straps were removed in v2.17; the enclosure now sits in the cradle/side keepers.

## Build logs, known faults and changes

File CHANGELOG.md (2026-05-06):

# CHANGELOG.md

## v2.17 - 2026-05-06

- Vented Pi cassette trays with long airflow slots through the cassette floors; verified each cassette exports as one connected component.
- Removed UGREEN straps and strap towers/fixtures; UGREEN now rests in the low cradle/side keepers.
- Added top fan guard between the upward fan and Mac mini. It is a lightweight lid-integrated Noctua-style grid rather than a second raw imported Noctua STL, because importing the high-triangle grille twice caused OpenSCAD assembly exports to time out.
- Revalidated clearances encoded in CAD: Pi ghost top at 109mm, top fan bottom at 135mm, leaving 26mm modelled clearance; front cassette has 26.2mm pocket depth for a 25mm fan and 124.5mm mounting-hole spacing.
- Re-exported printable STLs and preview STLs with no warnings; all printable parts are single connected components.

## v2.16 - 2026-05-05

- Confirmed stack order for front airflow: outside/fingers/dust side has the Noctua grille; fan ghost is now behind it inside the cassette pocket, blowing into the duct.
- Slimmed walls/floor/front cassette clips further: walls 1.8mm, base floor 5mm, smaller front tongues/receiver rails/screw bosses.
- Added more side-wall fan cable clips sized for Noctua USB fan leads routing back to the Pi USB area; removed isolated rear slack clips that created disconnected islands.
- Lowered Mac mini support elevation: top fan remains under the lid, Mac now has a modest 10mm outlet plenum rather than a tall perch.
- Fixed reintroduced disconnected tongue/clip islands; exports have no warnings and main printable parts are single connected components.

## v2.13 - 2026-05-05

- Reduced plastic: wall thickness 2.4mm → 2.0mm, base floor 8mm → 6mm, body height 164mm → 160mm, smaller Pi gantry posts/beams, leaner Mac risers, smaller cassette screw bosses, lighter Pi cassettes/UGREEN straps.
- Added STL preview exports: `fitted_parts_preview.stl`, `fitted_with_hardware_preview.stl`, and `front_fan_cassette_body.stl`.
- Updated the browser STL viewer dropdown to include fitted/full assembly preview options.
- Fixed simplified Pi cassette pull lip overlap so fitted preview exports as one connected component.
- Added `PRINT_NOTES.md` explaining PETG settings and Support PLA usage as slicer support-interface material, not something encoded in STL.

## v2.12 - 2026-05-05

- Re-integrated the scaled Noctua grille into `front_fan_cassette.stl` so the cassette and grille print as one part.
- Kept the cassette intake open behind the grille with a large circular/square relief through-cut.
- Simplified Pi cassettes to low trays: base/side guides/rear stop only, no tall top retention rails.
- Added `fitted_parts` preview mode for the assembled printable modules.
- Added `fitted_with_hardware` preview mode showing Mac mini, UGREEN, Pi stacks, and both 140mm fan ghosts fitted together.
- Regenerated STLs and previews with no export warnings; printable single modules are one connected component except `ugreen_straps.stl`, which intentionally contains two straps.

## v2.10 - 2026-05-05

- Split the Noctua grille out as a separate removable printable part: `front_noctua_grille.stl`.
- Removed the fused/imported grille from `front_fan_cassette.stl`; the cassette now has a visibly open 132mm circular intake.
- Added `front_noctua_grille` to export/validation scripts and `parts_manifest.json`.
- Regenerated STLs and validation outputs with no export warnings.

## v2.9 - 2026-05-05

- Added Bobby-supplied `references/noctua_120mm_high_efficiency_grill.stl`.
- Imported the real Noctua 120mm high-efficiency grille into the front cassette and scaled it to the 140mm fan envelope.
- Added small connector pads so the imported grille and cassette body export as one connected printable component.
- Regenerated all STLs: component check passes for all single printable modules; `ugreen_straps.stl` remains two intentional strap components.
- Export completed without OpenSCAD warnings.

## v2.8 - 2026-05-05

- Reduced material by lowering wall thickness from 3.0mm to 2.4mm, reducing the base floor from 14mm to 8mm, and trimming body height from 172mm to 164mm while retaining top-fan/Pi clearance.
- Replaced the crude front grille with a Noctua-inspired swept radial grille: curved struts, outer/inner connection rings, and screw-pad bridges.
- Regenerated STLs with no OpenSCAD export warnings.
- Connected-component check: all single printable parts are one component; `ugreen_straps.stl` intentionally has two components because it contains two separate straps.
- Approximate solid volume dropped from ~1694cm³ to ~1486cm³ across exported STLs, about 12% less before slicer infill settings.

## v2.7 - 2026-05-05

- Ran connected-component checks on exported STLs and removed actual disconnected/floating islands.
- Rebuilt the front cassette boolean so the fan pocket/opening is cut first and the grille is added back as real connected open bars.
- Connected UGREEN side keepers and strap towers down to the base deck.
- Removed floating upper receiver nubs from the base; retention now lives on the removable Pi cassettes.
- Rebuilt Pi cassettes as connected, OpenSCAD-simple meshes with no export warnings.
- Reworked UGREEN strap cutout so each strap is one connected frame; the straps STL intentionally contains two separate straps.

## v2.6 - 2026-05-05

- Changed top fan topology: the 140x25mm fan now mounts underneath the lid, inside the upper duct, rather than occupying the Mac saddle support volume.
- Raised the base duct height to leave roughly 16mm clearance between Pi cassette top and the underside of the top fan envelope.
- Reworked top fan geometry to low screw/locator pads rather than a solid block.
- Preserved an 18mm outlet plenum between the lid/top-fan outlet and Mac mini guide rails.
- Validated and regenerated all printable STLs and preview renders after the topology change.

## v2.5 - 2026-05-05

- Added printable gantry supports under the elevated Pi cassette receiver rails; the guides no longer float above the UGREEN bay.
- Support posts sit outside the UGREEN footprint and cross-beams sit above the UGREEN top clearance.
- Validated and regenerated all printable STLs plus preview renders after the support fix.

## v2.4 - 2026-05-05

- Enlarged the base and front cassette height back to a true 140mm fan envelope.
- Hollowed the rear of the front fan cassette with a 25mm fan pocket for mounting a real Noctua-style 140mm fan.
- Kept screw-through mounting holes and a 126mm circular airflow opening through the printed front grille/filter face.

## v2.3 - 2026-05-05

- Lowered Pi cassette rear pull lips from 11mm to 7mm so installed cassettes clear the physically seated lid envelope.
- Reworked front fan cassette receivers into real side-wall clearance channels instead of solid butt blocks.
- Corrected the UGREEN inspection ghost to match the cradle support height.
- Changed the default assembly view to show physically seated lid and front cassette placement rather than a semi-exploded inspection pose.
- Installed OpenSCAD CLI on the Pi, validated all six printable modules, regenerated STLs, and added hosted preview assets under `preview/`.
- Remaining print-critical measurements are still required before final print: exact UGREEN enclosure, Pi/HAT stack thickness, fan model/hole spacing, rear plug/bend depths, and Mac mini M4 power-button position.

## v2.2 - 2026-05-04

- Replaced the front KOYA text grille with a decorative diamond/ring support pattern.
- Revised the front fan grille again to a more circular radial/ring pattern.
- Revised the front fan grille to a curved swirl/ring pattern.
- Added a rear-loading filter-media pocket to the front fan cassette; printed plastic supports the filter, removable mesh/foam performs dust capture.
- Added four corner Mac saddle stanchions so the Mac guide rails visibly sit on the lid/top-fan-frame perimeter while leaving the central underside airflow path open.
- Shortened UGREEN support legs by reducing the underside tunnel from 24mm to 14mm, lowering the UGREEN and Pi stack.
- Recessed the top 140mm fan frame 10mm into the lid/ceiling and compacted the base duct height.
- Reduced case depth from 238mm to 208mm and rear plenum from 50mm to 28mm.
- Removed the internal fan splitter and guide vanes to keep the Pi airflow path open and less visually cluttered.
- Replaced cube fan ghosts with Noctua-style 140mm inspection ghosts showing frame, round opening, hub, struts, blades, pads and screw holes.
- Added named join-detail modules for front cassette receivers and lid support rails.
- Added `assembly_exploded` export plus inspection script output so connector directions are visible in OpenSCAD/STL review.
- Added side-wall fan cable clips and inspection ghost routes for front/top USB fan leads to rear Pi USB area, avoiding the primary airflow stream.
- Kept the post-fan duct open after the 140mm front fan.
- Reworked the UGREEN cradle to side rails only, with no solid shelf and no crosswise front/rear stops blocking enclosure grilles.
- Replaced continuous UGREEN support rails with thin peg legs and small pads to open the underside airflow path.
- Added a clear lower airflow tunnel under the UGREEN enclosure using side tunnel rails.
- Removed the rear cable comb posts from the primary airflow stream and enlarged the rear exhaust/cable opening.
- Increased Mac saddle lift to give roughly 18mm clear plenum above a 25mm top fan in the assembly view.
- Increased base duct height to the 140mm fan envelope and corrected Pi cassette assembly placement so holders sit below the upper fan volume.
- Reworked Pi receivers and cassettes from full-height rails to low-profile edge guides with small upper anti-tip tabs.
- Added a separate assembly-inspection export script for reviewing how modules fit together without treating the assembly as printable.
- Aligned UGREEN strap export geometry with base duct strap towers in the assembly.
- Added vertical strap-tower screw clearance through the base duct UGREEN cradle.
- Added Bambu Lab P1S build-volume assertions for individual printable modules.
- Validated and exported all six printable modules with OpenSCAD CLI.
- Dimensions still requiring real-world measurement: UGREEN bare enclosure, assembled Pi + Waveshare HAT stack thickness, exact 140mm fan model/hole spacing, rear cable plug depths and bend radii, and Mac mini M4 power-button position.

## v2.1

- Corrected UGREEN to sit below the Pi cassettes.
- Corrected Pi cassettes to sit above UGREEN bay.
- Clipped KOYA grille within front fan cassette face.
- Kept Mac mini saddle as corner-guide only to preserve underside airflow.
- Kept rear open for exhaust and cable routing.

## Next

- Validate with real hardware measurements.
- Export individual printable STLs.
- Slice on Bambu P1S.

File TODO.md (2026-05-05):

# TODO.md

## Immediate CAD tasks

- [ ] Import `dual_pi5_macmini_v2_1_corrected_stack_koya.scad` into this repo.
- [ ] Render assembly view in OpenSCAD.
- [ ] Check UGREEN/Pi collision visually using `SHOW_GHOSTS = true`.
- [ ] Export each part separately.
- [ ] Slice parts in Bambu Studio for Bambu P1S.
- [ ] Check support requirements.
- [ ] Add screw/rubber mount detail for exact fan model.
- [ ] Add measured UGREEN dimensions.
- [ ] Add measured Pi stack thickness.
- [ ] Add measured Mac mini power-button cut-out position.

## Possible design improvements

- [ ] Add captive nut pockets or heat-set insert pockets for fan cassette.
- [ ] Add rubber foot recesses.
- [ ] Add optional dust-filter slot in front of fan cassette.
- [ ] Add removable diffuser plate under Mac mini top fan.
- [ ] Add cable labels or cable comb refinements.
- [ ] Add versioned STL export manifest.

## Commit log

2026-05-06 Update KOYA wind tunnel case exports
    [base_duct.stl, dual_pi5_macmini_v2_1_corrected_stack_koya.scad, fitted_parts_preview.stl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]
2026-05-07 Update wind tunnel airflow and cable routing
    - widen Pi gap and convert Pi cassettes to open-frame rails
    - remove top fan grille restriction and add low Mac upper fan retainer
    - add fan/Mac cable routing hooks including RJ45 lane ghosts
    - refresh exported STLs, airflow summaries, and validation artifacts
    [base_duct.stl, cable_route_ghosts.stl, dual_pi5_macmini_v2_1_corrected_stack_koya.scad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]
2026-05-07 Make cable holders adapter-safe and model UGREEN vents
    - change Mac roof cable holders from closed bridges to open J-hook saddles for adapter-ended cables
    - add vented UGREEN airflow surrogate slices alongside solid-block baseline
    - refresh airflow summaries/images and affected lid/assembly exports
    [cable_route_ghosts.stl, dual_pi5_macmini_v2_1_corrected_stack_koya.scad, fitted_parts_preview.stl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]
2026-05-07 Split Pi support frame out of base duct
    - remove integrated cantilevered Pi gantry and lid ledges from base duct
    - add four M3 base bosses for a removable Pi frame bridge
    - export pi_frame_bridge upside-down for support-light printing
    - replace printed base cable lips with floor zip-tie slots
    - update export/validation scripts and README assembly notes
    [base_duct.stl, dual_pi5_macmini_v2_1_corrected_stack_koya.scad, fitted_parts_preview.stl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]
2026-05-07 Clarify Pi frame boss mounting feet
    - add explicit round feet to Pi frame bridge that sit on base bosses
    - keep M3 clearance holes through frame feet and base bosses
    - refresh base, Pi frame, and assembly exports
    [base_duct.stl, dual_pi5_macmini_v2_1_corrected_stack_koya.scad, fitted_parts_preview.stl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]
2026-05-07 Convert Pi frame mount to PLA clip-in pegs
    - replace M3 screw interface with chunky PLA tapered clip pegs on the base
    - add C-slotted feet to the removable Pi frame for press/snap fit
    - keep frame export support-light and refresh assembly/base exports
    - update README assembly notes for screwless Pi frame install
    [base_duct.stl, dual_pi5_macmini_v2_1_corrected_stack_koya.scad, fitted_parts_preview.stl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]
2026-05-08 Add reversible aesthetic pass for KOYA enclosure
    [dual_pi5_macmini_v2_1_corrected_stack_koya.scad]
2026-05-08 Adapt upper cooler for dual Noctua NF-F12 fans
    [dual_pi5_macmini_v2_1_corrected_stack_koya.scad]
2026-05-08 Correct NF-F12 layout and rerun airflow checks
    [airflow_variant_sweep.csv, base_duct.stl, dual_pi5_macmini_v2_1_corrected_stack_koya.scad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]
2026-05-09 Add Mac mini power rocker
    [dual_pi5_macmini_v2_1_corrected_stack_koya.scad]
2026-05-09 Correct Mac mini power rocker position
    [dual_pi5_macmini_v2_1_corrected_stack_koya.scad]
2026-05-09 Reduce support material for lid and base
    [dual_pi5_macmini_v2_1_corrected_stack_koya.scad]
2026-05-09 Simplify Pi cage sockets and correct Mac button
    [dual_pi5_macmini_v2_1_corrected_stack_koya.scad]
2026-05-09 Flatten Mac saddle and integrate Pi holders
    [dual_pi5_macmini_v2_1_corrected_stack_koya.scad]
2026-05-09 Separate Mac power rocker window
    [dual_pi5_macmini_v2_1_corrected_stack_koya.scad]
2026-05-09 Mirror Mac power rocker mount
    [dual_pi5_macmini_v2_1_corrected_stack_koya.scad]
2026-05-09 Remove Mac mini wire guides
    [dual_pi5_macmini_v2_1_corrected_stack_koya.scad]
2026-05-12 Add Surface Pro 9 cooling stand v1
    [assembly_v1.stl, fan_tray_front_v1.stl, fan_tray_rear_v1.stl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]
2026-05-12 Revise Surface cooling stand with airflow and fasteners
    [assembly_v2.stl, fan_tray_front_v2.stl, fan_tray_rear_v2.stl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]
2026-05-12 Soften Surface cooling stand shroud design
    [assembly_v3.stl, bottom_dust_grille_v3.stl, fan_tray_front_v3.stl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]
2026-05-12 Reduce material in Surface cooling stand
    [assembly_v4.stl, bottom_dust_grille_v4.stl, fan_tray_front_v4.stl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]
